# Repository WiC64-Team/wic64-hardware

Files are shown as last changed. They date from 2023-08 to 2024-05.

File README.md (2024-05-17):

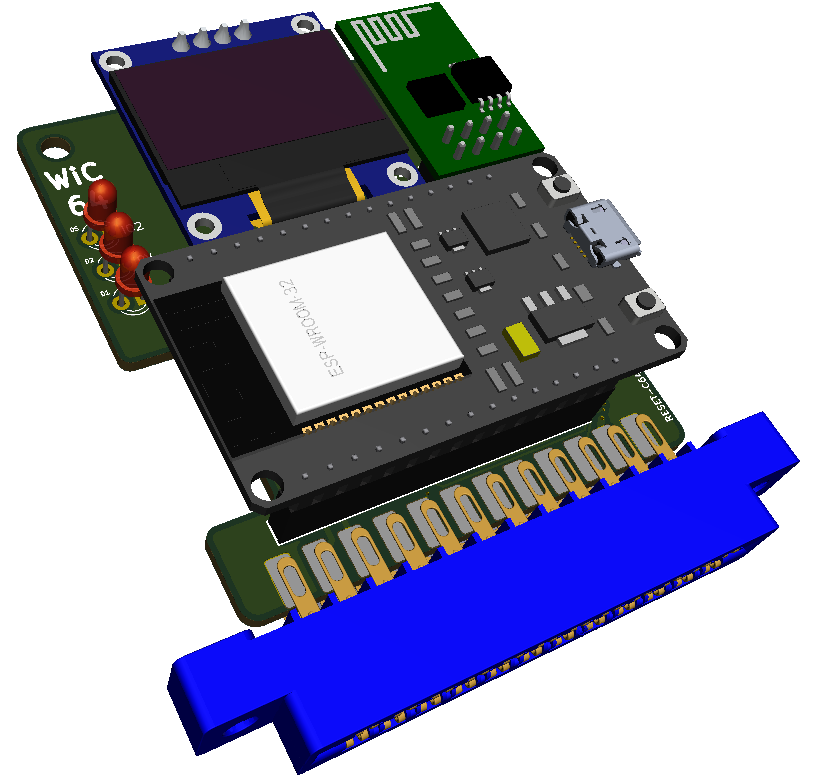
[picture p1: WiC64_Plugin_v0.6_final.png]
Model


<p xmlns:cc="http://creativecommons.org/ns#" xmlns:dct="http://purl.org/dc/terms/"><a property="dct:title" rel="cc:attributionURL" href="https://wic64.com">WiC64</a> by <a rel="cc:attributionURL dct:creator" property="cc:attributionName" href="https://wic64.com">GMP</a> is licensed under <a href="https://creativecommons.org/licenses/by/4.0/?ref=chooser-v1" target="_blank" rel="license noopener noreferrer" style="display:inline-block;">CC BY 4.0</a></p>

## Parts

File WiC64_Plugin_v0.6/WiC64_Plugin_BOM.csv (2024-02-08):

ID | Designator | Package | Quantity | Designation
2 | Q11,Q3,Q4,Q1,Q5,Q2,Q6,Q9,Q7,Q8,Q10 | SOT-23 | 11 | BSS138 | BSS138
3 | D3 | D_SOD-123 | 1 | 1N5819 | 1N5819/B5819W
4 | D2 | LED_D3.0mm yellow | 1 | 9V | HL-304S33YD
5 | D1 | LED_D3.0mm red | 1 | 5V | HL-304S9AD
7 | C1 | CP_6.3x11mm_hor | 1 | 220uF/25V | LKMC1101E221MF
8 | C2 | CP_6.3x11mm_hor | 1 | 100uF/25V | ERM1EM101E11OT
9 | SW1 | SW_Tactile_SPST_Angled_9mm_switch_height | 1 | RESET-C64 | TC-1102N-C-DS-B
10 | D4 | Diode_Bridge_Diotec_SO-DIL-Slim | 1 | DB107S | DB107S
11 | R1,R2,R3,R4,R5,R6,R7,R8,R9,R10,R11,R12,R13,R14,R15,R16,R17,R18,R19,R20,R21,R22,R25 | R_0603_1608Metric | 23 | 10k | 0603WAF1002T5E
12 | R23 | R_0603_1608Metric | 1 | 4k7 | 0603WAF4701T5E
13 | R24 | R_0603_1608Metric | 1 | 12k | 0603WAF1202T5E
14 | SW2 | SW_Tactile_SPST_Angled_9mm_switch_height | 1 | Function | TC-1102N-C-DS-B
15 | D5 | LED_D3.0mm green | 1 | IO2 | TJ-L3FYTGCGMCGLFLC2G-A5
16 | R26 | R_0603_1608Metric | 1 | 3k9 | 0603WAF3901T5E
17 | XBrd1 | PinSocket_1x04_P2.54mm_Vertical | 1 | Conn_01x04_Female | female header 1*4pin 2.54mm, height 8.51mm
18 | XU2 | PinSocket_2x04_P2.54mm_Vertical | 1 | Conn_02x04_Female | female header 2*4pin 2.54mm,height 8.51mm
24 | XU1-1,XU1-2 | PinSocket_1x15_P2.54mm_Vertical | 2 | Conn_01x15_Female | female header 1*15pin 2.54mm, height 8.51mm

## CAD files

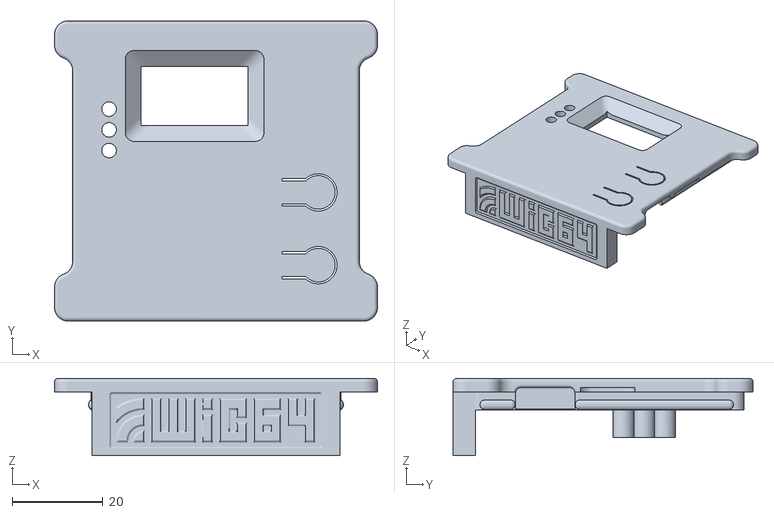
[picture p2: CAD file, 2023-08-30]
Case/WiC64_Plugin_Case_Top_0.9.1.stl
71.0 x 66.0 x 17.0

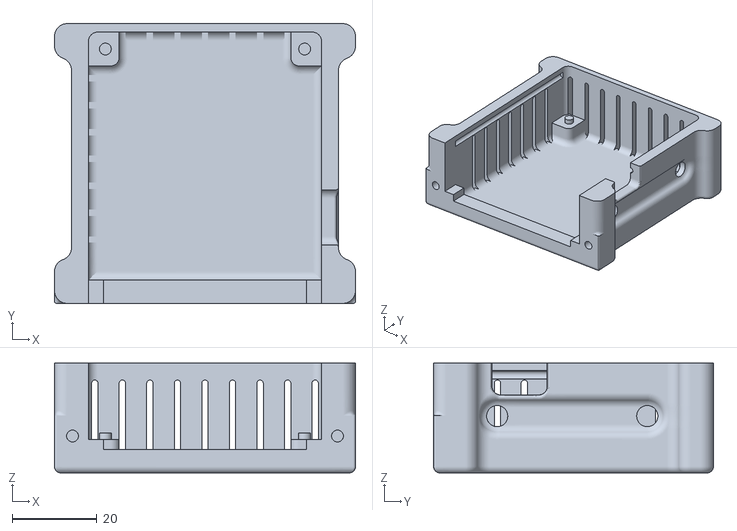
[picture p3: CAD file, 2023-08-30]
Case/WiC64_Plugin_Case_Bottom_0.9.1.stl
71.0 x 66.0 x 25.9

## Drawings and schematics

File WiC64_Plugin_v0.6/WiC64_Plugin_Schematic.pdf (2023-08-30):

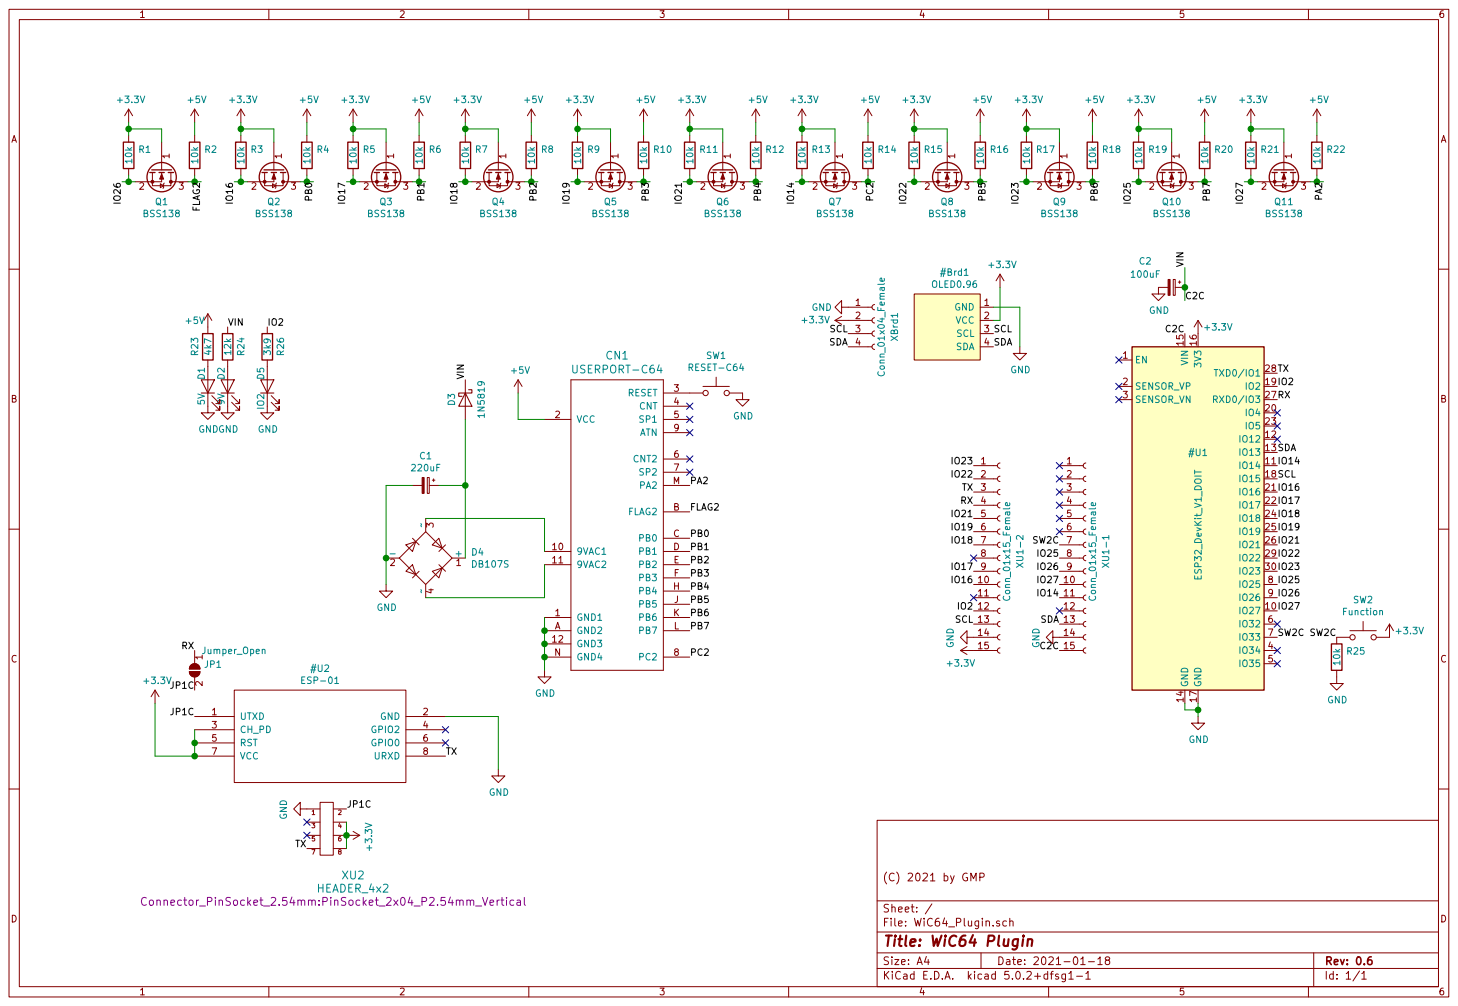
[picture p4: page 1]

File: WiC64_Plugin.sch Sheet: / (C) 2021 by GMP

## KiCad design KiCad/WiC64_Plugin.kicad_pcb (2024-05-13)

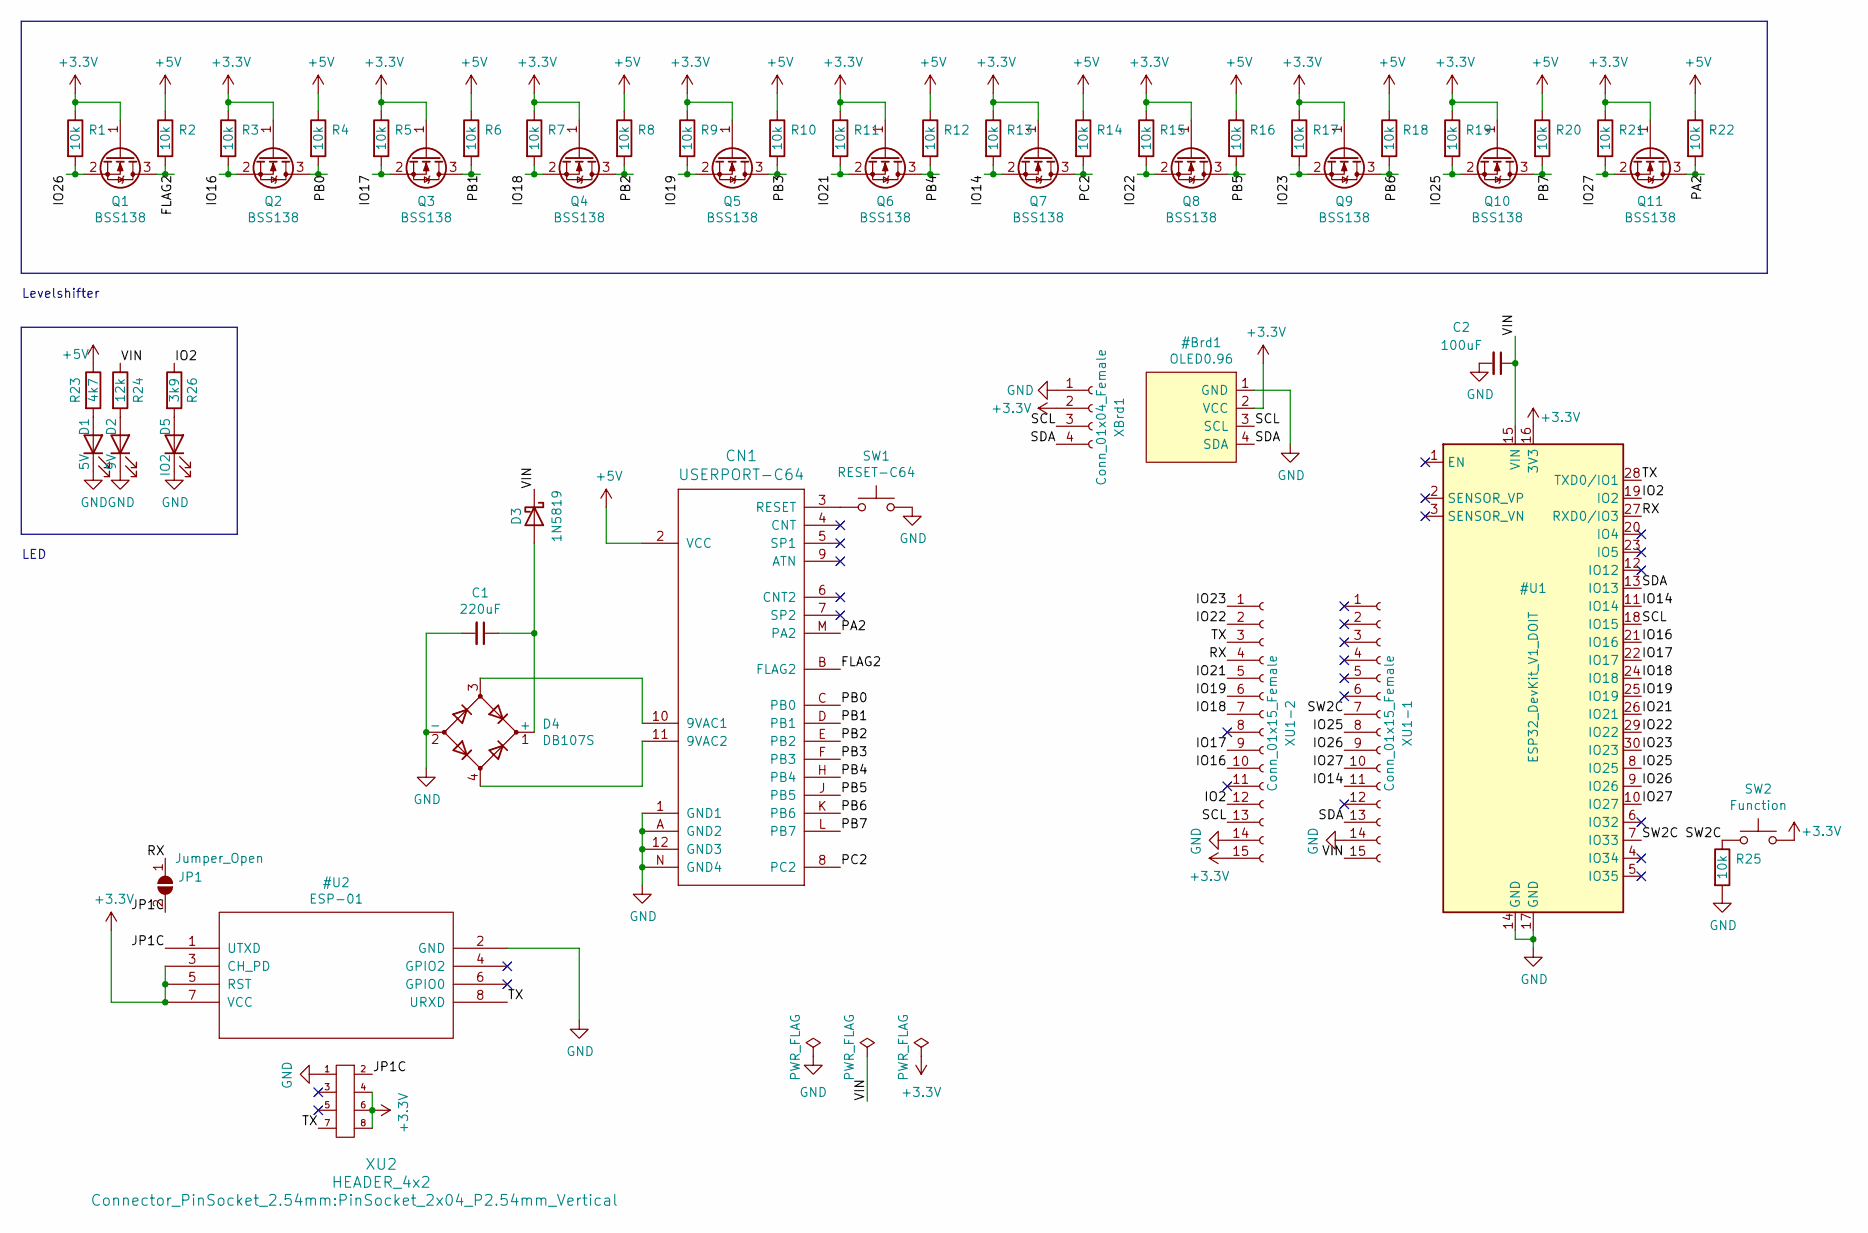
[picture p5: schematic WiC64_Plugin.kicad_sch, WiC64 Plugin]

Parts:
C1: 220uF; CP_6.3x11mm_hor; LCSC C269997
C2: 100uF; CP_6.3x11mm_hor; LCSC C106598
CN1: USERPORT-C64; UPS24CONN
D1: 5V; LED_D3.0mm; LCSC C568936
D2: 9V; LED_D3.0mm; LCSC C568937
D3: 1N5819; D_SOD-123; LCSC C402219
D4: DB107S; Diode_Bridge_Diotec_SO-DIL-Slim; LCSC C190797
D5: IO2; LED_D3.0mm; LCSC C331056
JP1: Jumper_Open; SolderJumper-2_P1.3mm_Open_RoundedPad1.0x1.5mm
Q1, Q2, Q3, Q4, Q5, Q6, Q7, Q8, Q9, Q10, Q11: BSS138; SOT-23; LCSC C112239
R1, R2, R3, R4, R5, R6, R7, R8, R9, R10, R11, R12, R13, R14, R15, R16, R17, R18, R19, R20, R21, R22, R25: 10k; R_0603_1608Metric; LCSC C25804
R23: 4k7; R_0603_1608Metric; LCSC C23162
R24: 12k; R_0603_1608Metric; LCSC C22790
R26: 3k9; R_0603_1608Metric; LCSC C23018
SW1: RESET-C64; SW_Tactile_SPST_Angled_PTS645Vx58-2LFS; LCSC C406160
SW2: Function; SW_Tactile_SPST_Angled_PTS645Vx58-2LFS; LCSC C406160
XBrd1: Conn_01x04_Female; PinSocket_1x04_P2.54mm_Vertical
XU1-1, XU1-2: Conn_01x15_Female; pin_socket_15
XU2: HEADER_4x2; PinSocket_2x04_P2.54mm_Vertical

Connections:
+5V: CN1.2 (VCC), R2.1, R4.1, R6.1, R8.1, R10.1, R12.1, R14.1, R16.1, R18.1, R20.1, R22.1, R23.1
/FLAG2: CN1.B (FLAG2), Q1.3 (D), R2.2
/PA2: CN1.M (PA2), Q11.3 (D), R22.2
/PB0: CN1.C (PB0), Q2.3 (D), R4.2
/PB1: CN1.D (PB1), Q3.3 (D), R6.2
/PB2: CN1.E (PB2), Q4.3 (D), R8.2
/PB3: CN1.F (PB3), Q5.3 (D), R10.2
/PB4: CN1.H (PB4), Q6.3 (D), R12.2
/PB5: CN1.J (PB5), Q8.3 (D), R16.2
/PB6: CN1.K (PB6), Q9.3 (D), R18.2
/PB7: CN1.L (PB7), Q10.3 (D), R20.2
/PC2: CN1.8 (PC2), Q7.3 (D), R14.2
unnamed: CN1.10 (9VAC1), D4.3
unnamed: CN1.11 (9VAC2), D4.4
unnamed: CN1.3 (RESET), SW1.1
unnamed: D1.2 (A), R23.2
unnamed: D2.2 (A), R24.2
unnamed: C1.1, D3.2 (A), D4.1 (+)
unnamed: D5.2 (A), R26.2

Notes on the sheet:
Levelshifter
LED

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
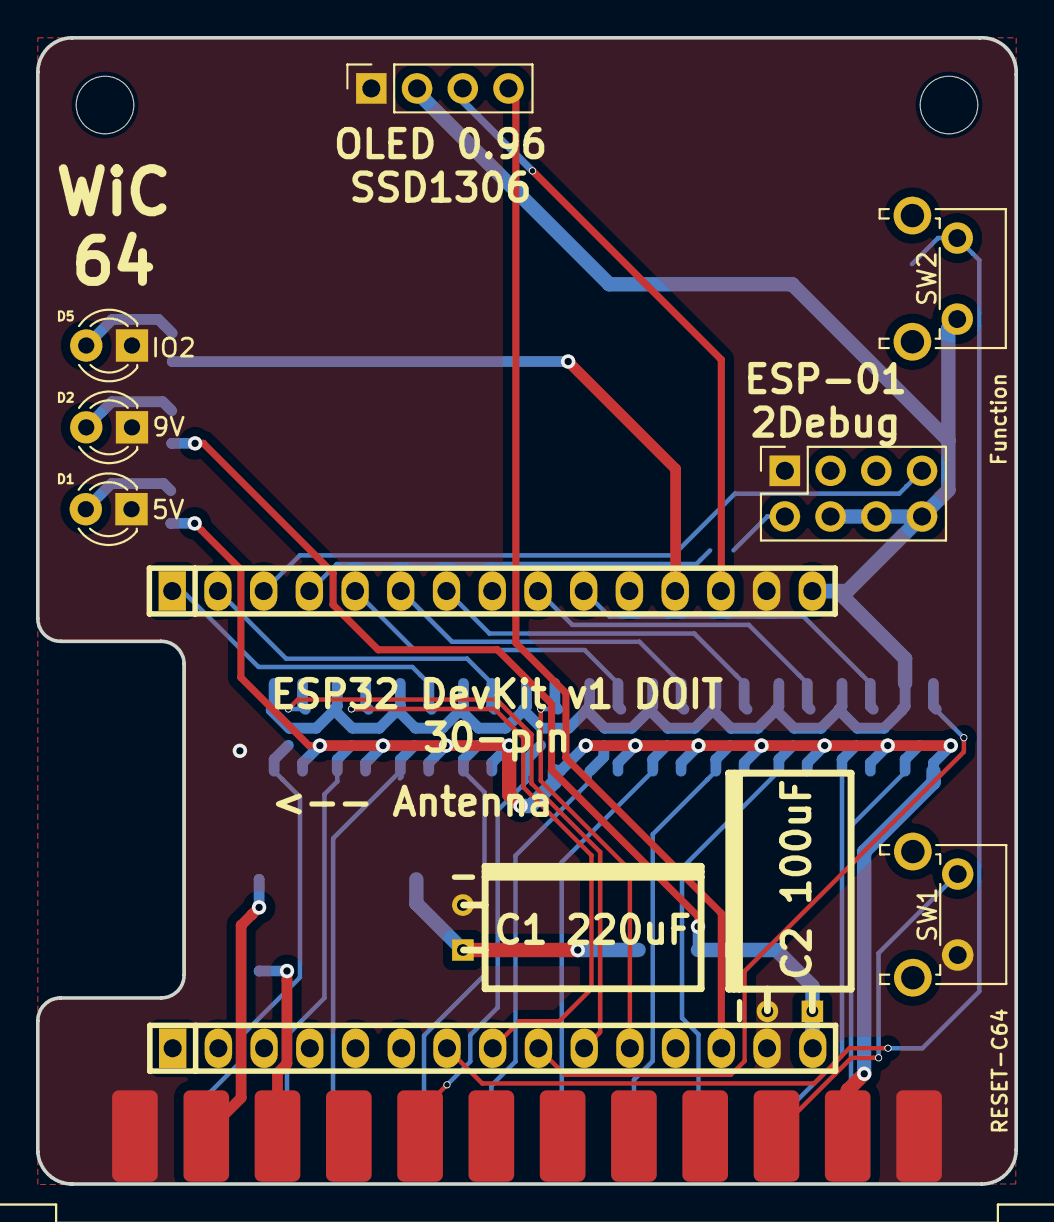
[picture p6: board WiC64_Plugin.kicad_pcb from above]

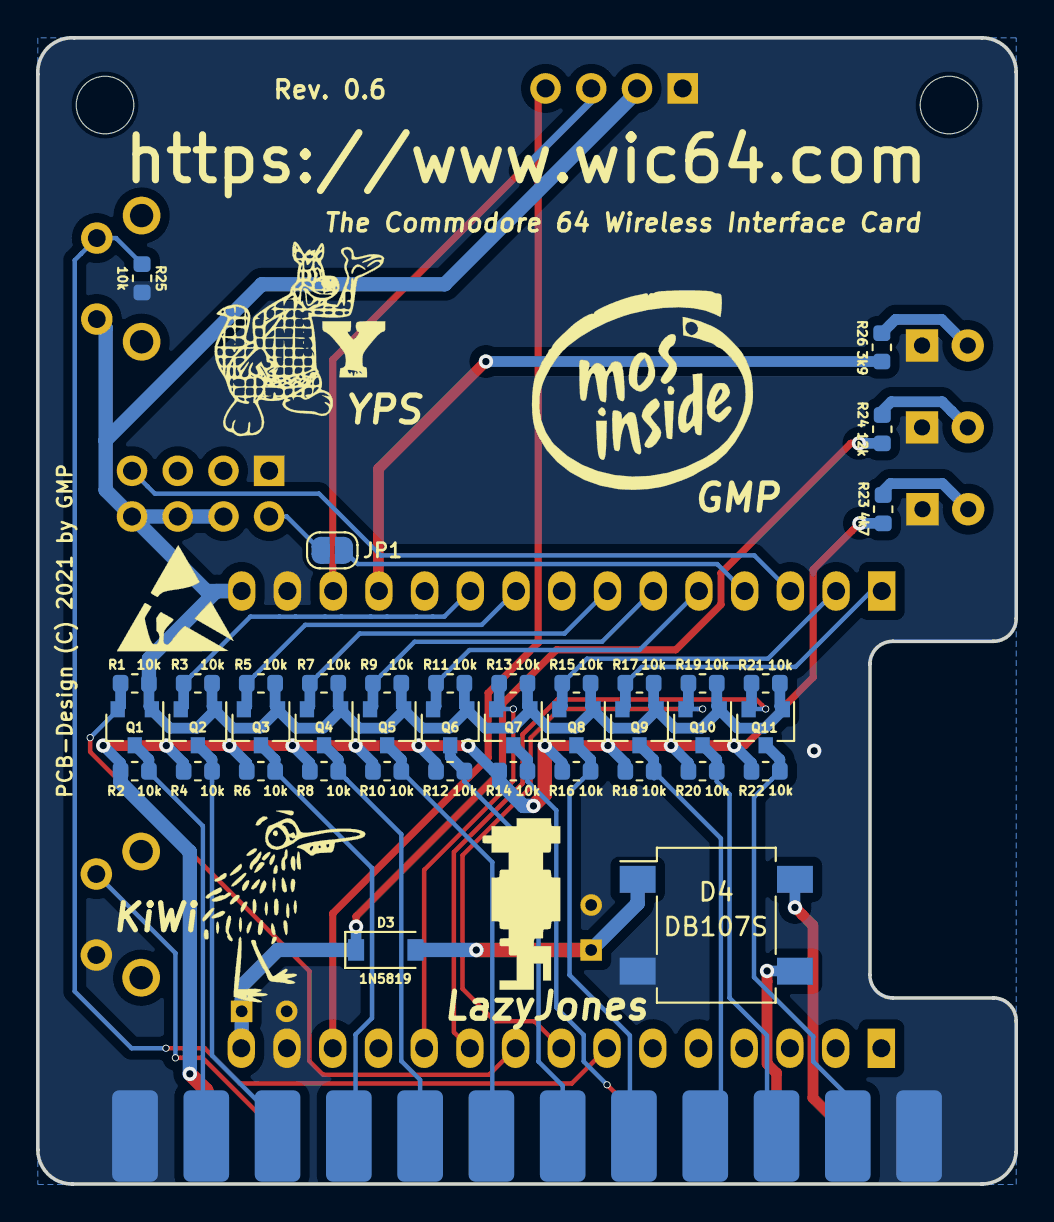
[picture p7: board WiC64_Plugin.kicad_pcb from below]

Board: 2 copper layers, 54.4 x 63.7 mm, 52 parts (40 on the bottom side), 40 nets.

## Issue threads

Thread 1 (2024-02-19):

Excessive heat on ESP32 AMS1117 regulator due to high rectified 9v.

Ming-Kerr, 2024-02-19:
Hello.
This circuit actually destroyed a few of the cheap clone ESP's I tried with it, and the "official" ESP32 AMS1117 still runs unnervingly hot, right at the edge of voltage input specs.
I fixed this entirely by removing diode D3 and wiring a 7805 regulator's IN and GND pins direct to the bridge rectifier +/-, then the output pin to VIN just past where D3 was with a short jumper wire. Turning the 7805 upside down means it can be kept relatively neat and flush.
No concerns now. Neither gets particularly warm.
Even the cheap Chinese ESP32 clone's should survive with this change.

Cheers now.

GMP64, 2024-02-19:
Hello,
unfortunately, I have to disagree with you. Normally, the circuit does not destroy anything. According to the data sheet, the voltage regulator is designed for a maximum temperature of up to 125°C and can withstand a maximum input voltage of 15V. Yes, it gets hot. Measured at full load with a thermal imaging camera, we were at 80 degrees.
As you write that several ESPs have been destroyed, please check your power supply unit. There is probably a fundamental problem on the 9Volt~ line. We have not yet received any negative feedback from others to this extent.
Best wishes.

Ming-Kerr, 2024-02-19:
9v line on the PSU is fine, measuring just under 10v with a MM. The regulator was getting hotter than 80C.
The cheap Chinese ones that died have different components around the AMS1117, e.g. a diode swapped with a zero ohm resistor and I suspect the capacitors were specced with too low voltage ratings, expecting 5v.
Anyway, I'm happy with my particular solution that is keeping everything cool.

GMP64, 2024-02-19:
Yes, I agree with you. We can't know exactly where the modules come from and whether the manufacturer adheres exactly to the circuit specifications. That's a big problem. And this zero-ohm resistor has already caused us a lot of trouble.

Ming-Kerr, 2024-02-19:
I will close the issue now, as that aspect is more related to the odd off kilter batch of ESP32's.
Just thought I'd point out one workaround if anyone else comes across the same sort of thing with very hot AMS as well.

Cheers now.

Closed 2024-02-19.

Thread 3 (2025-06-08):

Overheating issues?

Sgw32, 2025-06-08:
Hi :)

I recently assembled one unit and gave it a test. Everything is just great, I am impressed.
However, after half an hour of work it started to reboot in cyclic way. It was also very very hot.
I see from the schematic that ESP32 is powered from rectified 9V directly. I think that may be an issue.
LDO LM1117/AMS1117 installed on most of ESP32 devboards is not capable of such power dissipation.

I would recommend to install a DC/DC on existing boards to convert rectified 9V to 5V or even to 3.3V directly.
I will probably make a hardware revision but first I'll sell all fabricated boards(license permits it) and after that will make a new batch with a dcdc. I would recommend a small +5V DC/DCs from Taobao or Aliexpress. They are tiny enough to fit inside the existing enclosure

Best regards,
Fedor

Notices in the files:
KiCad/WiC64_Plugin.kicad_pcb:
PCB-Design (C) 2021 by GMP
